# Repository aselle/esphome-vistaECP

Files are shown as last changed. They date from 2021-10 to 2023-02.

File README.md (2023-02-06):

# Honeywell/Ademco Vista ECP ESPHome custom component and library

## This fork provides a PCB

This is based on work that was discussed on the main fork issues at 
https://github.com/Dilbert66/esphome-vistaECP/issues/49

Based on the work of the main fork, I created a design and pcb. At the time, the main fork did not provide a fully isolated schematic, which I wanted if I was going to use this on my system.  I invetsigated several designs and settled on this one for my uses. The issue describes a lot of the possibilites. In the end, I used 3 optocouplers and 2 transistors.
You should be able to get the board manufactured cheaply e.g. on JLCPCB.

This is provided with no warranty implied or explicit. I can not be held responsible for you using this work. While, I have tested this in my own equipment for over a year, I suspect the main fork is better tested, so I would recommend this approach only for advanced users who know how to use an oscilloscope.
 
* circuit/v1-manufacture-files
  * has gerber, pdf schematic and case stl files
* circuit/kicad
  * KiCad source for the pcb.

Here's the isolated schematic

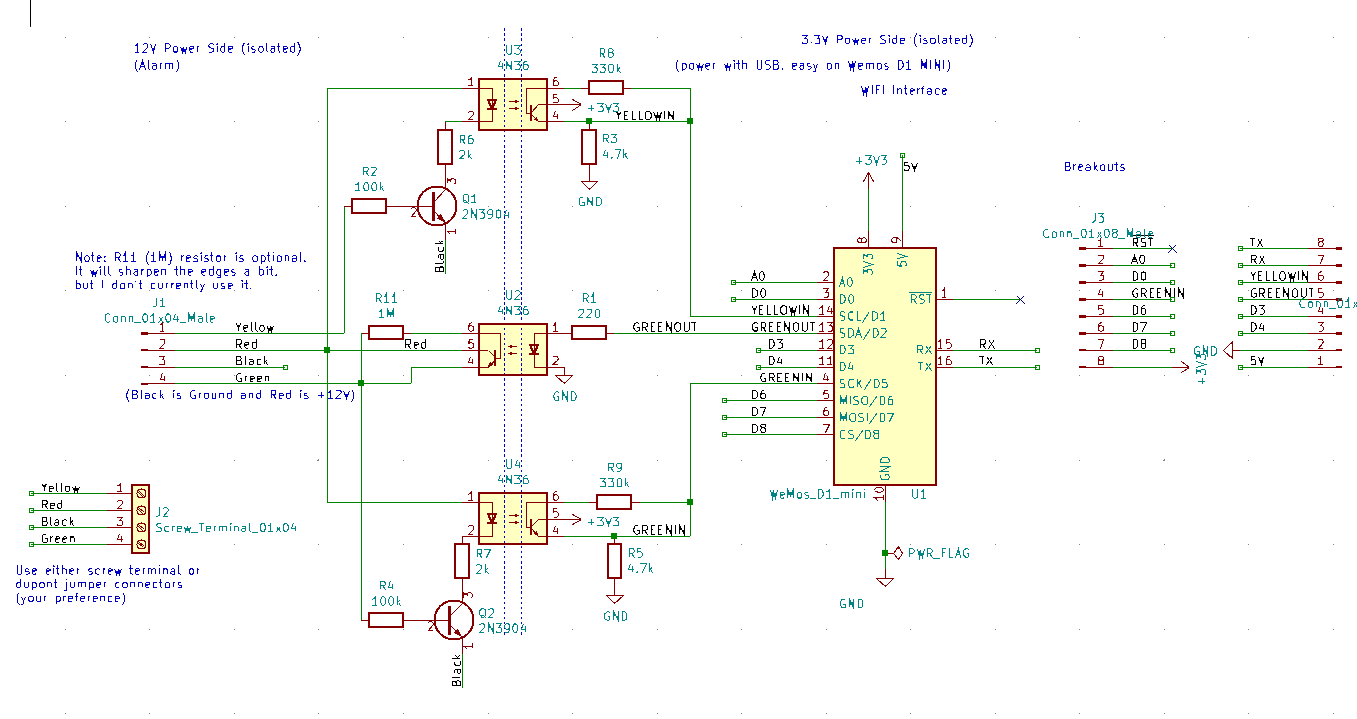
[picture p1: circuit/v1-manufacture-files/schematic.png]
Image of schematic


Here is what the manufactured product looks like

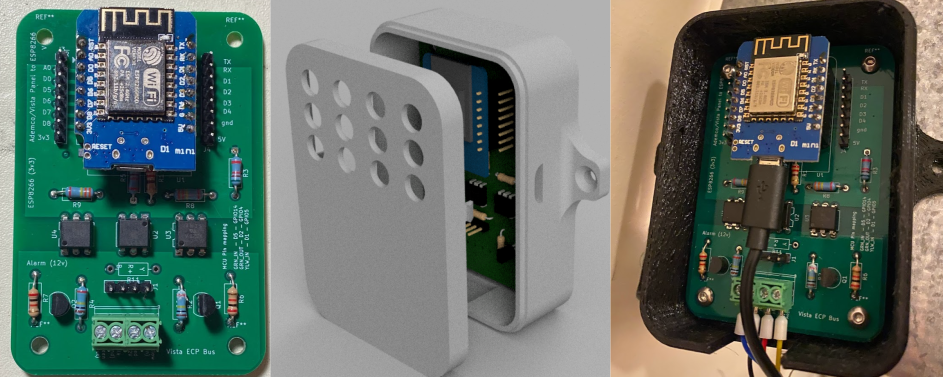
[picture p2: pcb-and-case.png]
Image of case and pcb


## Main fork documentation

This is an implementation of an ESPHOME custom component and ESP Library to interface directly to a Safewatch/Honeywell/Ademco Vista 15/20 alarm system using the ECP interface and very inexpensive ESP8266/ESP32 modules .  The ECP library code is based on the arduino source code from Mark Kimsal's repository located at  https://github.com/TANC-security/keypad-firmware.  It has been  completely rewritten as a class and adapted to work on the ESP8266/ESP32 platform using interrupt driven communications and pulse timing. A custom modified version of Peter Lerup's ESPsoftwareserial library (https://github.com/plerup/espsoftwareserial) was also used for the serial communications to work more efficiently within the tight timing of the ESP8266 interrupt window. 

To compensate for the limitations of the minimal zone data sent by the panel, a time to live (TTL) attribute for each faulted zone was used.  The panel only sends fault messages when a zone is faulted or alarmed and does not send data when the zone is restored, therefore the TTL timer is used to reset a zone after a preset duration once it stops receiving those fault/alarm messages for that zone.  You can tweak the TTL setting in the YAML.  The default timer is set to 30 seconds.  I've also added persistent storage and recovery for zone status in the event of a power failure or reboot of the ESP.  The system will use persistent storage to recover the last known status of the zone on restart.

From documented info, it seems that some panels send an F2 command with extra system details but the panel I have here (Vista 20P version 3.xx ADT version) does not.  Only the F7 is available for zone and system status in my case but this is good enough for this purpose. 

As far as writing on the bus and the request to send pulsing sequence, most documentation only discusses keypad traffic and this only uses the the 3rd pulse.  In actuality the pulses are used as noted below depending on the device type requesting to send:
```
Panel pulse 1. Addresses 1-7, expander board (07), etc
Panel pulse 2. Addresses 8-15 - zone expanders, relay modules
Panel pulse 3. Addresses 16-23 - keypads
```
For example, a zone expander that has the address 07, will send it's address on the first pulse only and will send nothing for the 2nd and 3rd pulse.  A keypad with address 16, will send a 1 bit pulse for pulse1 and pulse2 and then it's encoded address on pulse 3. This info was determined from analysis using a zone expander board and Pulseview to monitor the bus. 

If you are not familiar with ESPHome , I suggest you read up on this application at https://esphome.io and home assistant at https://www.home-assistant.io/.   The library class itself can be used outside of the esphome and home assistant systems.  Just use the code as is without the vistalalarm.yaml and vistaalarm.h files and call it's functions within your own application.  

To use this software you simply place the vistaAlarm.yaml file in your main esphome directory, then copy the *.h and *.cpp files from the vistaEcpInterface directory to a similarly named subdirectory (case sensitive) in your esphome main directory and then compile the yaml as usual. The directory name is in the "includes:" option of the yaml.

##### Notes: 
* If you use the zone expanders and/or LRR functions, you might need to clear CHECK messages for the LRR and expanded zones from the panel on boot or restart by entering your access code followed by 1 twice. eg 12341 12341 where 1234 is your access code.

The yaml attributes should be fairly self explanatory for customization. The yaml example also shows how to setup named zones. 

## Features:

* Full zone expander emulation (4219/4229) which will give you  an additional 8 zones to the system per emulated expander plus associated relay outputs. Currently the library will provide emulation for 2 boards for a total of 16 additionals zones. You can even use free pins on the chip as triggers for those zones as well. 

* Relay module emulation. (4204). The system can support 4 module addresses for a total of 16 relay channels. 

* Long Range Radio (LRR) emulation (or monitoring) statuses for more detailed status messages

* Zone status - Open, Busy, Alarmed and Closed with named zones

* Arm, disarm or send any sequence of commands to the panel

* Status indicators - fire, alarm, trouble, armed stay, armed away, instant armed, armed night,  ready, AC status, bypass status, chime status,battery status, check status, zone and relay channel status fields.

* Optional ability to monitor other devices on the bus such as keypads, other expanders, relay boards, RF devices, etc. This requires the #define MONITORTX to be uncommented in vista.h as well as the addition of two resistors (R4 and R5) to the circuit as shown in the schematic.   This adds another serial interrupt routine that captures and decodes all data on the green tx line.  If enabled this data will be used to update zone statuses for external modules.

The following services are published to home assistant for use in various scripts. 

	alarm_disarm: Disarms the alarm with the user code provided, or the code specified in the configuration.
	alarm_arm_home: Arms the alarm in home mode.
	alarm_arm_away: Arms the alarm in away mode.
	alarm_arm_night: Arms the alarm in night mode (no entry delay).
	alarm_trigger_panic: Trigger a panic alarm.
        alarm_trigger_fire: Trigger a fire alarm.
	alarm_keypress: Sends a string of characters to the alarm system. 

## Example in Home Assistant

Image of HASS example

The returned statuses for Home Assistant are: armed_away, armed_home, armed_night, pending, disarmed,triggered and unavailable.  

Sample Home Assistant Template Alarm Control Panel configuration with simple services (defaults to partition 1):

```
alarm_control_panel:
  - platform: template
    panels:
      safe_alarm_panel:
        name: "Alarm Panel"
        value_template: "{{states('sensor.vistaalarm_system_status')}}"
        code_arm_required: false
        
        arm_away:
          - service: esphome.vistaalarm_alarm_arm_away
                  
        arm_home:
          - service: esphome.vistaalarm_alarm_arm_home
          
        arm_night:
          - service: esphome.vistaalarm_alarm_arm_night
            data_template:
              code: '{{code}}' #if you didnt set it in the yaml, then send the code herefschema
          
        disarm:
          - service: esphome.vistaalarm_alarm_disarm
            data_template:
              code: '{{code}}'                    
```

## Services

- Basic alarm services. These services default to partition 1:

	- "alarm_disarm", Parameter: "code" (access code)
	- "alarm_arm_home" 
	- "alarm_arm_night", Parameter: "code" (access code)
	- "alarm_arm_away"
	- "alarm_trigger_panic"
	- "alarm_trigger_fire"

- Intermediate command service. Use this service if you need more versatility such as setting alarm states on any partition:

	- "set_alarm_state",  Parameters: "partition","state","code"  where partition is the partition number from 1 to 8, state is one of "D" (disarm), "A" (arm_away), "S" (arm_home), "N" (arm_night), "P" (panic) or "F" (fire) and "code" is your panel access code (can be empty for arming, panic and fire cmds )

- Generic command service. Use this service for more complex control:

	- "alarm_keypress",  Parameter: "keys" where keys can be any sequence of keys accepted by your panel. For example to arm in night mode you set keys to be "xxxx33" where xxxx is your access code. 
    
    - "set_zone_fault",Parameters: "zone","fault" where zone is a zone from 9 - 48 and fault is 0 or 1 (0=ok, 1=open)
       The zone number will depend on what your expander address is set to.

## Wiring

### Non-isolated simple version

ecpinterface

### Alternative version using transistors instead of an optocoupler for transmit

ecpinterface-noopto

### Ground Isolated version

ecpinterface-isolated

## Wiring Notes

* Optocouplers should have a minimum CTR of 50. Recommendations are the 4N35 or TLP521. You can vary the resistor values for the simple version but keep the ratio similar for the voltage dividers R2/R3 and R4/R5. R1 should not be set below 150 ohm. Resistor values are chosen to minimize load on ECP bus while still providing full output signals on the optocouplers. 
* My goal was to keep the design as simple as possible without causing any bus load or interference with maximum signal fidelity.  Since the transmit circuit required high side switching I opted to use an optocoupler since I had a few on hand and it simplified the amount of components needed but proved to have it's own issues as far as CTR requirements.  For those that would prefer not using optocouplers due to availability or other reasons, i've provided a version using transistors for the transmit circuit instead.  

## OTA updates
In order to make OTA updates, connection switch in frontend should be switched to OFF since the  ECP library is using interrupts.

## MQTT with HomeAssistant
If your preference is to use MQTT instead of ESPHOME, you can use the Arduino sketch from the MQTT-Example directory. It supports pretty much all functions of the ESPHOME implementation.  To use, edit the configuration items at the top of the file for your setup then simply put the ino and all *.h and *.cpp vista library files (from directory /src/vistaEcpInterface) in the same sketch directory and compile.  Read the comments within the sketch for more details.   The sketch also supports ArduinoOTA (https://www.arduino.cc/reference/en/libraries/arduinoota/) that will enable you to update the code via wifi once the initial upload is done.  

## Custom Alarm Panel Card

I've added a sample lovelace alarm-panel card copied from the repository at https://github.com/GalaxyGateway/HA-Cards. I've customized it to work with this ESP library's services.   I've also added two new text fields that will be used by the card to display the panel prompts the same way a real keypad does. To configure the card, just place the alarm-panel-card.js file into the /config/www directory of your homeassistant installation and add a new resource in your lovelace configuration pointing to /local/alarm-panel-card.js.  You can then configure the card as shown below. Just substitute your service name to your application.

```
type: 'custom:alarm-keypad-card'
title: Vista_ESPHOME
unique_id: vista1
disp_line1: sensor.vistaalarm_line1
disp_line2: sensor.vistaalarm_line2
scale: 1
service_type: esphome
service: vistaalarm_alarm_keypress
status_A: AWAY
status_B: STAY
status_C: READY
status_D: BYPASS
status_E: TROUBLE
status_F: ''
status_G: ''
status_H: ''
sensor_A: binary_sensor.vistaalarm_away
sensor_B: binary_sensor.vistaalarm_stay
sensor_C: binary_sensor.vistaalarm_ready
sensor_D: binary_sensor.vistaalarm_bypass
sensor_E: binary_sensor.vistaalarm_trouble
button_A: STAY
button_B: AWAY
button_C: DISARM
button_D: BYPASS
button_F: <
button_G: '>'
button_E: ' '
button_H: ' '
cmd_A:
  keys: '12343'
cmd_B:
  keys: '12342'
cmd_C:
  keys: '12341'
cmd_D:
  keys: '12346#'
cmd_E:
  keys: ''
cmd_H:
  keys: ''
cmd_F:
  keys: <
cmd_G:
  keys: '>'
key_0:
  keys: '0'
key_1:
  keys: '1'
key_2:
  keys: '2'
key_3:
  keys: '3'
key_4:
  keys: '4'
key_5:
  keys: '5'
key_6:
  keys: '6'
key_7:
  keys: '7'
key_8:
  keys: '8'
key_9:
  keys: '9'
key_star:
  keys: '*'
key_pound:
  keys: '#'
key_right:
  keys: '>'
key_left:
  keys: <
beep: sensor.vistaalarm_beeps
view_pad: true
view_display: true
view_status: true
view_status_2: true
view_bottom: true

type: 'custom:alarm-keypad-card'
title: Vista_MQTT
unique_id: vista2
disp_line1: sensor.displayline1
disp_line2: sensor.displayline2
scale: 1
service_type: mqtt
service: publish
status_A: AWAY
status_B: STAY
status_C: READY
status_E: BYPASS
status_D: TROUBLE
status_F: ''
status_G: ''
status_H: ''
sensor_A: sensor.vistaaway
sensor_B: sensor.vistastay
sensor_C: sensor.vistaready
sensor_E: sensor.vistabypass
sensor_D: sensor.vistatrouble
button_A: STAY
button_B: AWAY
button_C: DISARM
button_D: BYPASS
cmd_A:
  topic: vista/Set/Cmd
  payload: '!12343'
cmd_B:
  topic: vista/Set/Cmd
  payload: '!12342'
cmd_C:
  topic: vista/Set/Cmd
  payload: '!12341'
cmd_D:
  topic: vista/Set/Cmd
  payload: '!12346#'
key_0:
  topic: vista/Set/Cmd
  payload: '!0'
key_1:
  topic: vista/Set/Cmd
  payload: '!1'
key_2:
  topic: vista/Set/Cmd
  payload: '!2'
key_3:
  topic: vista/Set/Cmd
  payload: '!3'
key_4:
  topic: vista/Set/Cmd
  payload: '!4'
key_5:
  topic: vista/Set/Cmd
  payload: '!5'
key_6:
  topic: vista/Set/Cmd
  payload: '!6'
key_7:
  topic: vista/Set/Cmd
  payload: '!7'
key_8:
  topic: vista/Set/Cmd
  payload: '!8'
key_9:
  topic: vista/Set/Cmd
  payload: '!9'
key_star:
  topic: vista/Set/Cmd
  payload: '!*'
key_pound:
  topic: vista/Set/Cmd
  payload: '!#'
view_pad: true
view_display: true
view_status: true
view_status_2: true
view_bottom: false
beep: sensor.vistabeeps

```


### sample sensor configuration for card using mqtt
```

sensor:

  - platform: mqtt
    state_topic: "vista/Get/DisplayLine/1"
    name: "DisplayLine1"

  - platform: mqtt
    state_topic: "vista/Get/DisplayLine/2"
    name: "DisplayLine2"

  - platform: mqtt
    state_topic: "vista/Get/Status/AWAY"
    name: "vistaaway"
    
  - platform: mqtt
    state_topic: "vista/Get/Status/STAY"
    name: "vistastay"
  
  - platform: mqtt
    state_topic: "vista/Get/Status/READY"
    name: "vistaready"

  - platform: mqtt
    state_topic: "vista/Get/Status/TROUBLE"
    name: "vistatrouble"

  - platform: mqtt
    state_topic: "vista/Get/Status/BYPASS"
    name: "vistabypass"
    
  - platform: mqtt
    state_topic: "vista/Get/Status/CHIME"
    name: "vistachime"    

```

## References 
You can checkout the links below for further reading and other implementation examples. Some portions of the code in the repositories below was used in creating the library.
* https://github.com/TANC-security/keypad-firmware
* https://github.com/cweemin/espAdemcoECP
* https://github.com/TomVickers/Arduino2keypad/

This project is licensed under the Lesser General Public License version 2.1, or (at your option) any later version as per it's use of other libraries and code. Please see COPYING.LESSER for more informatio

## Disclaimer

THIS HARDWARE AND SOFTWARE IS PROVIDED BY THE COPYRIGHT HOLDERS AND CONTRIBUTORS “AS IS” AND ANY EXPRESS OR IMPLIED WARRANTIES, INCLUDING, BUT NOT LIMITED TO, THE IMPLIED WARRANTIES OF MERCHANTABILITY AND FITNESS FOR A PARTICULAR PURPOSE ARE DISCLAIMED. IN NO EVENT SHALL THE COPYRIGHT OWNER OR CONTRIBUTORS BE LIABLE FOR ANY DIRECT, INDIRECT, INCIDENTAL, SPECIAL, EXEMPLARY, OR CONSEQUENTIAL DAMAGES (INCLUDING, BUT NOT LIMITED TO, PROCUREMENT OF SUBSTITUTE GOODS OR SERVICES; LOSS OF USE, DATA, OR PROFITS; OR BUSINESS INTERRUPTION) HOWEVER CAUSED AND ON ANY THEORY OF LIABILITY, WHETHER IN CONTRACT, STRICT LIABILITY, OR TORT (INCLUDING NEGLIGENCE OR OTHERWISE) ARISING IN ANY WAY OUT OF THE USE OF THIS SOFTWARE, EVEN IF ADVISED OF THE POSSIBILITY OF SUCH DAMAGE.

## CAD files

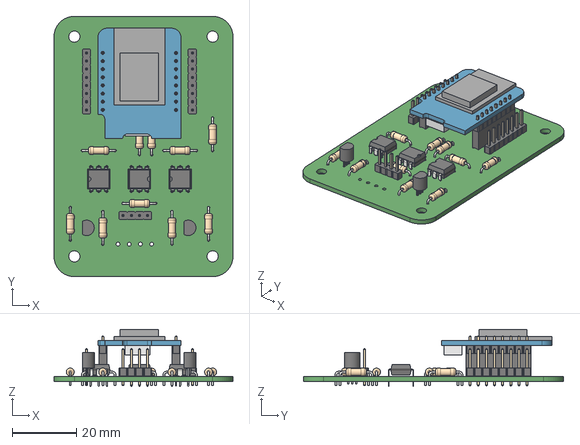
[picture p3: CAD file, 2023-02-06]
circuit/kicad/vista20p-alt.step
55.9 x 81.3 x 17.9 mm

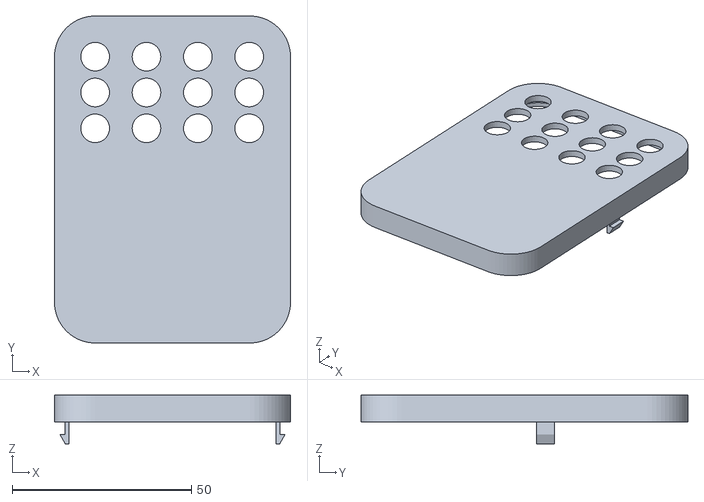
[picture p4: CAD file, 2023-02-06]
circuit/v1-manufacture-files/CaseTop.stl
65.9 x 91.3 x 13.6

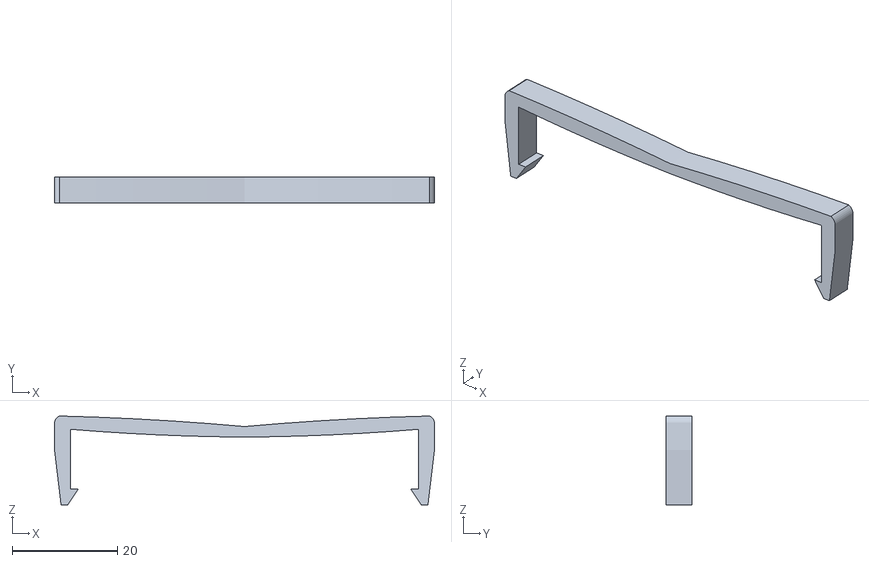
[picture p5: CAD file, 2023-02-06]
circuit/v1-manufacture-files/CaseClip.stl
72.2 x 5.00 x 16.9

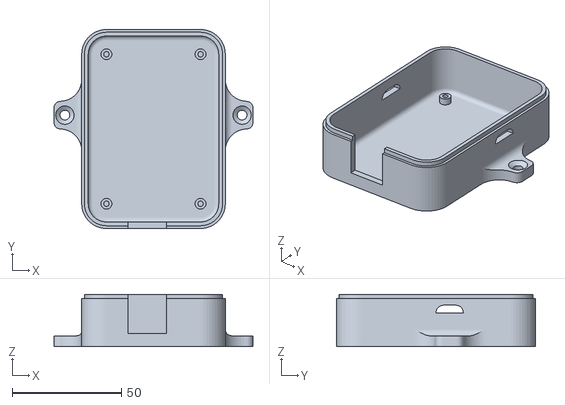
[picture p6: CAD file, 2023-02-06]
circuit/v1-manufacture-files/CaseBottom.stl
91.3 x 91.3 x 24.0

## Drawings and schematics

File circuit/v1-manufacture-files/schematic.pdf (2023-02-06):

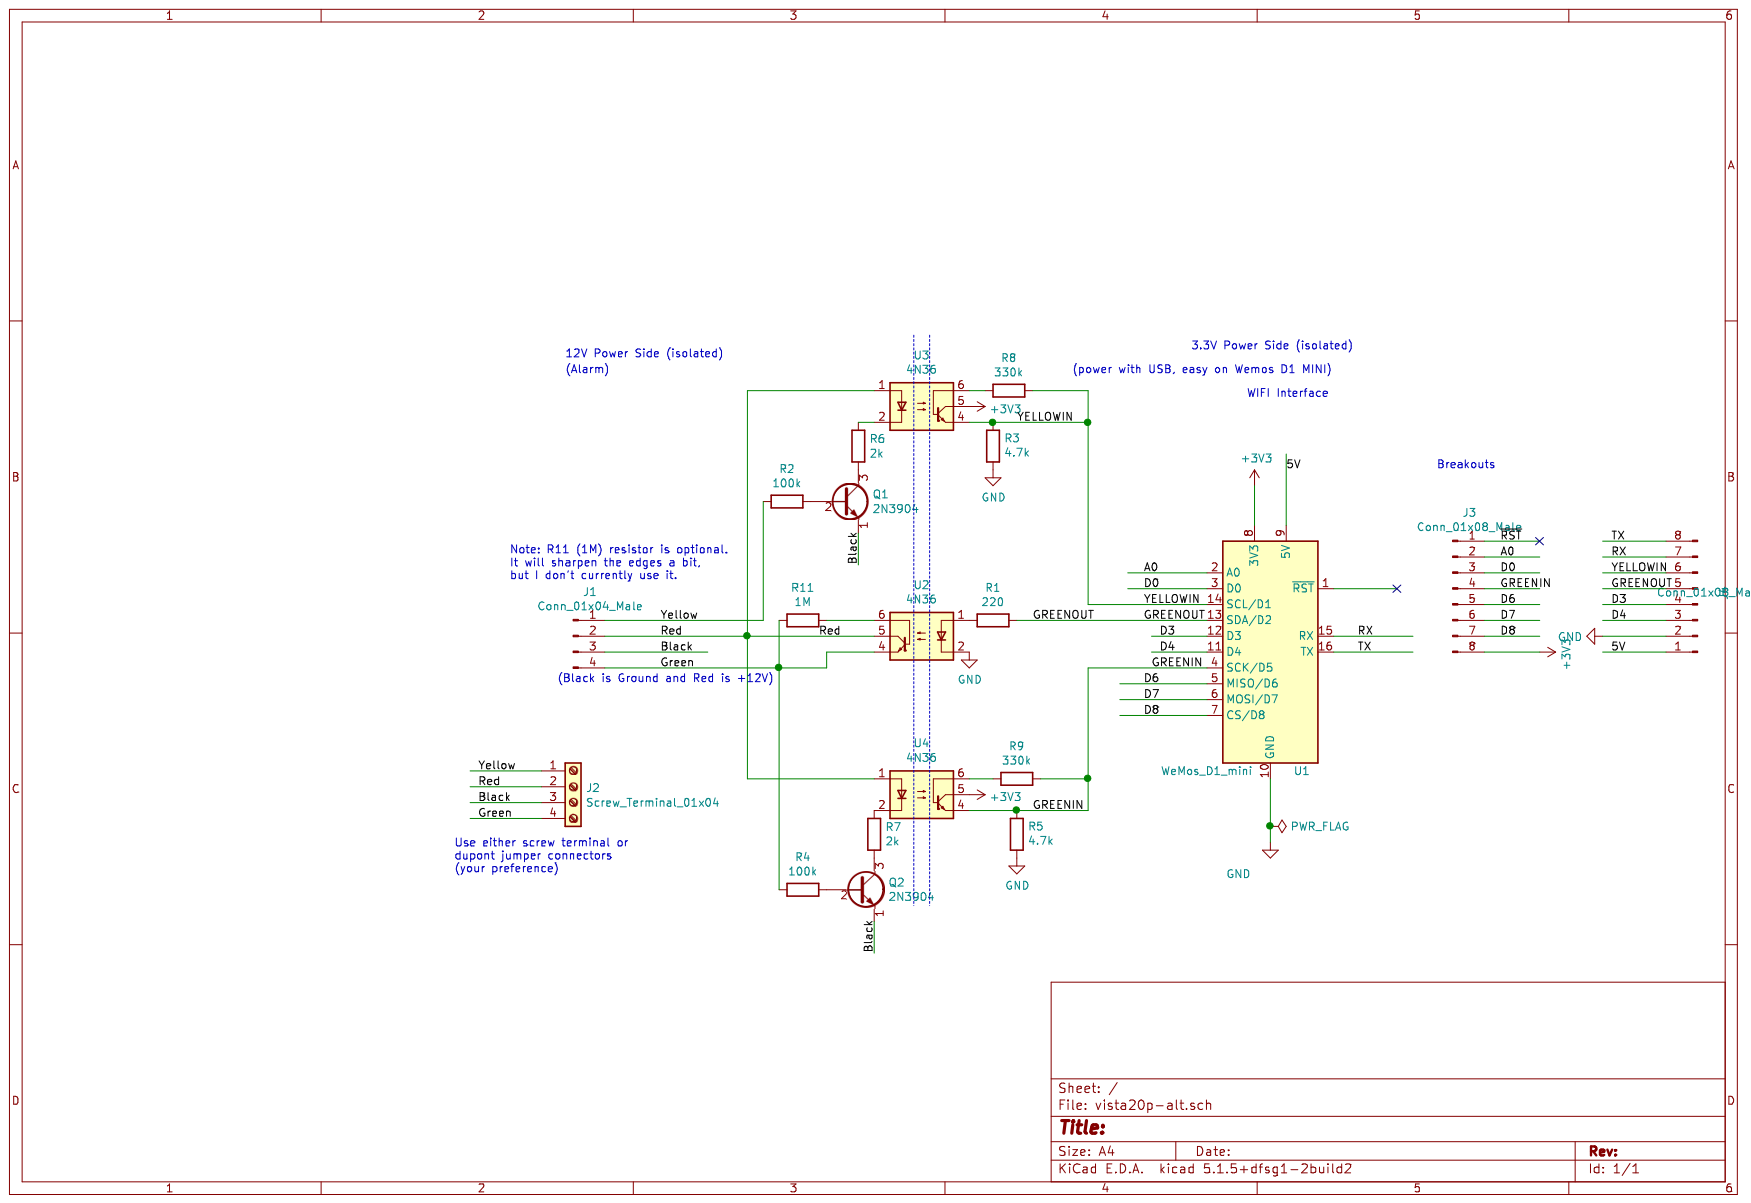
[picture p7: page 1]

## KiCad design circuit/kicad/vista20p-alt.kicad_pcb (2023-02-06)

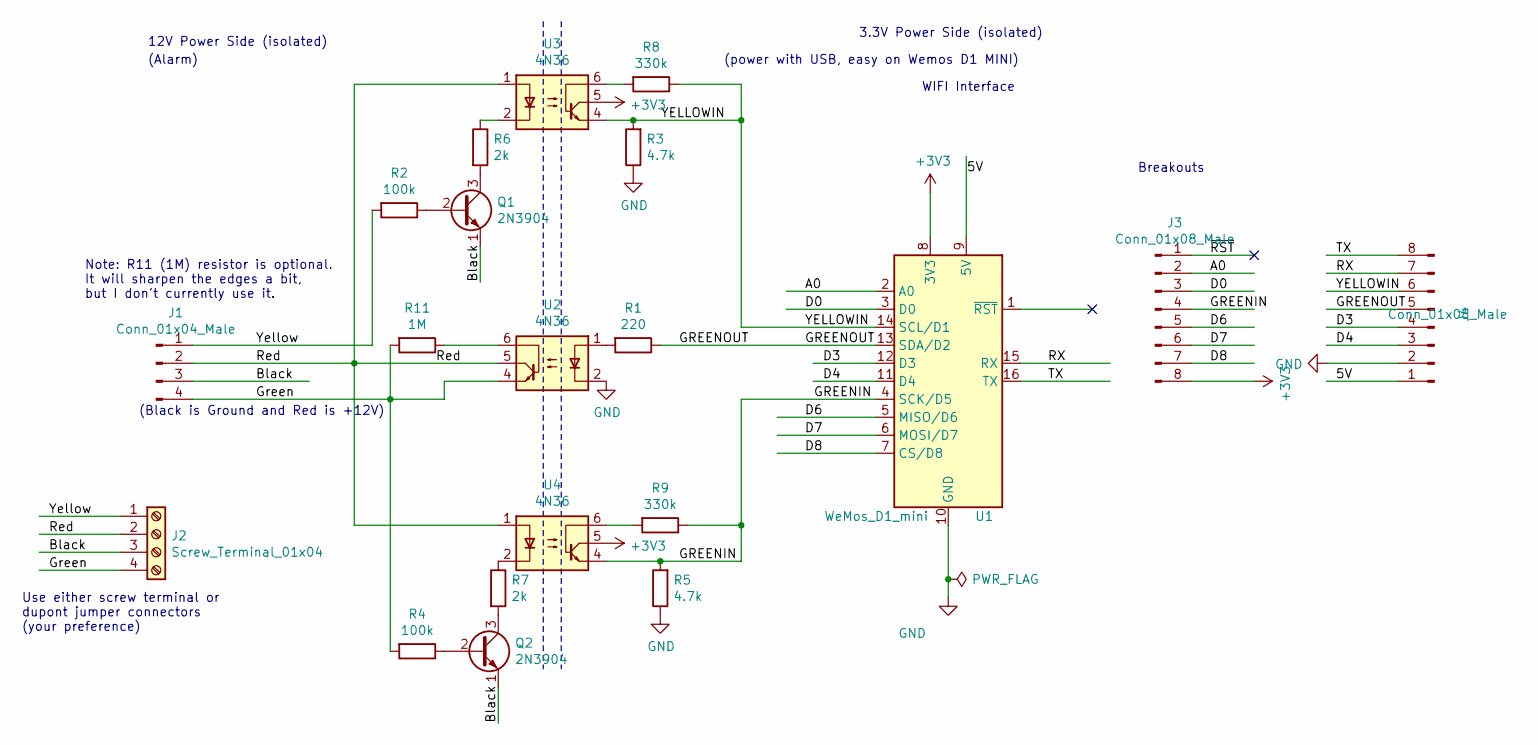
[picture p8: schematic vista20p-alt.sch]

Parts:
J1: Conn_01x04_Male; PinHeader_1x04_P2.54mm_Vertical
J2: Screw_Terminal_01x04; TerminalBlock_Phoenix_PT-1,5-4-3.5-H_1x04_P3.50mm_Horizontal
J3, J4: Conn_01x08_Male; PinHeader_1x08_P2.54mm_Vertical
Q1, Q2: 2N3904; TO-92_Inline
R1: 220; R_Axial_DIN0207_L6.3mm_D2.5mm_P10.16mm_Horizontal
R2, R4: 100k; R_Axial_DIN0207_L6.3mm_D2.5mm_P10.16mm_Horizontal
R3, R5: 4.7k; R_Axial_DIN0207_L6.3mm_D2.5mm_P10.16mm_Horizontal
R6, R7: 2k; R_Axial_DIN0207_L6.3mm_D2.5mm_P10.16mm_Horizontal
R8, R9: 330k; R_Axial_DIN0207_L6.3mm_D2.5mm_P10.16mm_Horizontal
R11: 1M; R_Axial_DIN0207_L6.3mm_D2.5mm_P10.16mm_Horizontal
U1: WeMos_D1_mini; WEMOS_D1_mini_light
U2, U3, U4: 4N36; DIP-6_W7.62mm

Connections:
+3V3: J3.8, U1.8 (3V3), U3.5, U4.5
/5V: J4.1, U1.9 (5V)
/A0: J3.2, U1.2 (A0)
/Black: J1.3, J2.3, Q1.1 (E), Q2.1 (E)
/D0: J3.3, U1.3 (D0)
/D3: J4.4, U1.12 (D3)
/D4: J4.3, U1.11 (D4)
/D6: J3.5, U1.5 (MISO/D6)
/D7: J3.6, U1.6 (MOSI/D7)
/D8: J3.7, U1.7 (CS/D8)
/GREENIN: J3.4, R5.2, R9.1, U1.4 (SCK/D5), U4.4
/GREENOUT: J4.5, R1.1, U1.13 (SDA/D2)
/Green: J1.4, J2.4, R4.2, R11.2, U2.4
/RX: J4.7, U1.15 (RX)
/Red: J1.2, J2.2, U2.5, U3.1, U4.1
/TX: J4.8, U1.16 (TX)
/YELLOWIN: J4.6, R3.2, R8.1, U1.14 (SCL/D1), U3.4
/Yellow: J1.1, J2.1, R2.2
/~RST: J3.1, U1.1 (~RST)
GND: J4.2, R3.1, R5.1, U1.10 (GND), U2.2
unnamed: Q1.2 (B), R2.1
unnamed: Q1.3 (C), R6.2
unnamed: Q2.2 (B), R4.1
unnamed: Q2.3 (C), R7.2
unnamed: R1.2, U2.1
unnamed: R6.1, U3.2
unnamed: R7.1, U4.2
unnamed: R8.2, U3.6
unnamed: R9.2, U4.6
unnamed: R11.1, U2.6

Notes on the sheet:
Use either screw terminal or dupont jumper connectors (your preference)
(power with USB, easy on Wemos D1 MINI)
WIFI Interface
(Alarm)
(Black is Ground and Red is +12V)
3.3V Power Side (isolated)
12V Power Side (isolated)
Breakouts
Note: R11 (1M) resistor is optional. It will sharpen the edges a bit, but I don't currently use it.

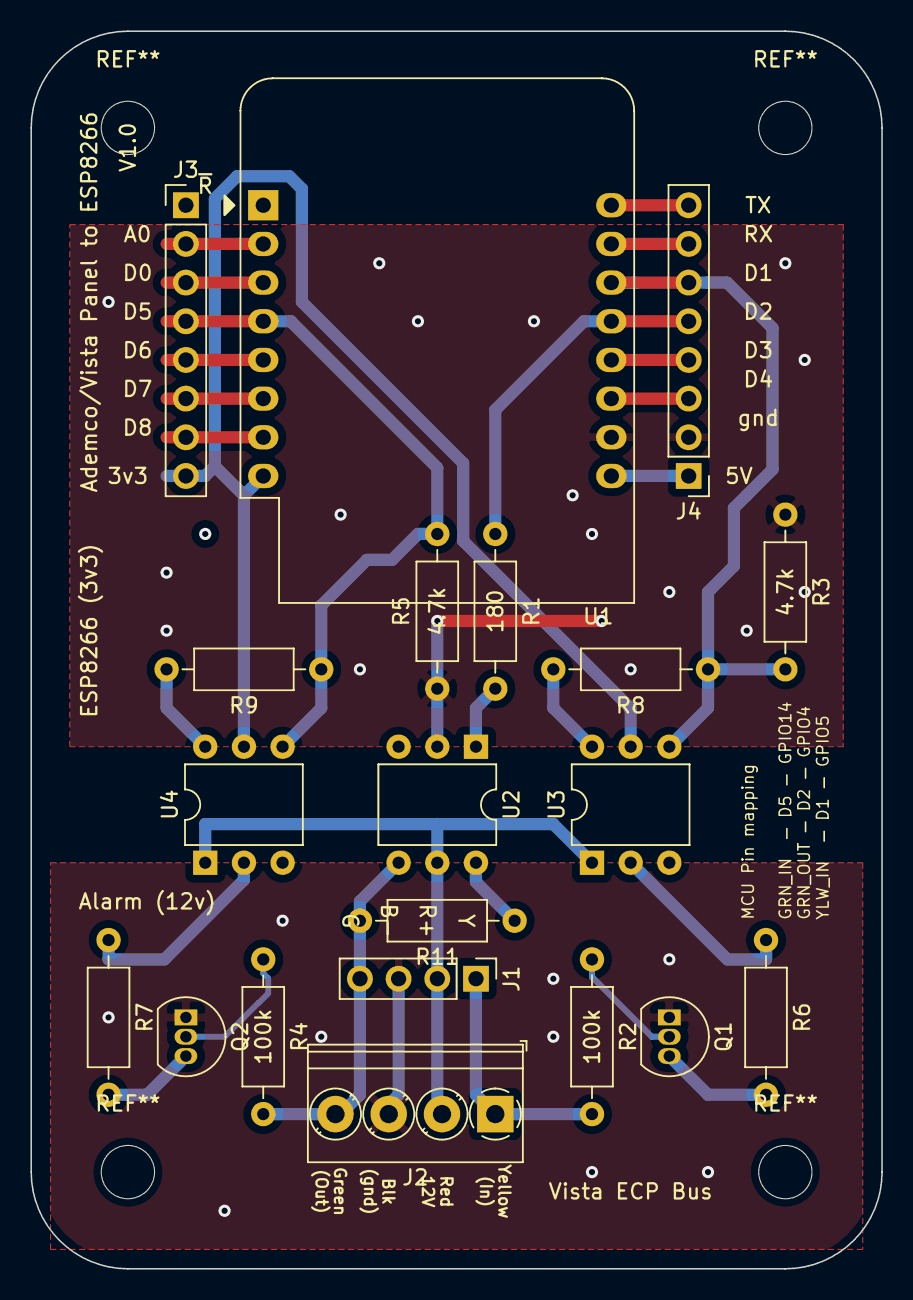
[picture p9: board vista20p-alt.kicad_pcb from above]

Board: 2 copper layers, 55.9 x 81.3 mm, 20 parts (0 on the bottom side), 30 nets.

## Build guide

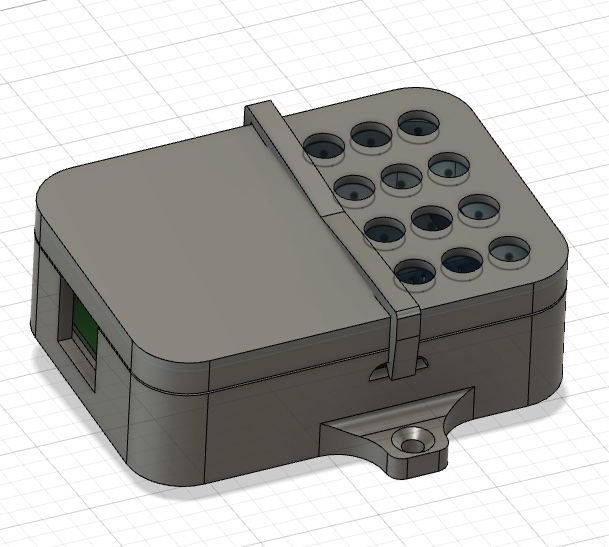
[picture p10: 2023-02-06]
circuit/v1-manufacture-files/CaseScreenshot.jpg

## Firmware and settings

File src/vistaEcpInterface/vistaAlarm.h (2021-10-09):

#include "esphome.h"

#include "vista.h"
 //for documentation see project at https://github.com/Dilbert66/esphome-vistaecp

#define KP_ADDR 16
#define MAX_ZONES 48

//default pins to use for serial comms to the panel
//The pinouts below are only examples. You can choose any other gpio pin that is available and not needed for boot.
//These have proven to work fine.
#ifdef ESP32
//esp32 use gpio pins 4,13,16-39 
#define RX_PIN 22
#define TX_PIN 21
#define MONITOR_PIN 18 // pin used to monitor the green TX line (3.3 level dropped from 12 volts
#else
#define RX_PIN 5
#define TX_PIN 4
#define MONITOR_PIN 14 // pin used to monitor the green TX line (3.3 level dropped from 12 volts
#define TX_ENABLE_PIN 12 // pin used to monitor the green TX line (3.3 level dropped from 12 volts
#endif

Stream * OutputStream = & Serial;
Vista vista(OutputStream);

void disconnectVista() {
    vista.stop();

}
enum sysState {
    soffline,
    sarmedaway,
    sarmedstay,
    sbypass,
    sac,
    schime,
    sbat,
    scheck,
    scanceled,
    sarmednight,
    sdisarmed,
    striggered,
    sunavailable,
    strouble,
    salarm,
    sfire,
    sinstant,
    sready,
    sarmed
};

class vistaECPHome: public PollingComponent, public CustomAPIDevice {
    public: vistaECPHome(char kpaddr = KP_ADDR, int receivePin = RX_PIN, int transmitPin = TX_PIN, int monitorTxPin = MONITOR_PIN, int txEnablePin=TX_ENABLE_PIN) ): kpaddr(kpaddr),
    rxPin(receivePin),
    txPin(transmitPin),
    txEnablePin(txEnablePin),
    monitorPin(monitorTxPin) {}

    // start panel language definitions
    const char *
        const FAULT = "FAULT";
    const char *
        const BYPAS = "BYPAS";
    const char *
        const ALARM = "ALARM";
    const char *
        const FIRE = "FIRE";
    const char *
        const CHECK = "CHECK";
    const char *
        const CLOSED = "CLOSED";
    const char *
        const OPEN = "OPEN";
    const char *
        const ARMED = "ARMED";

    const char *
        const STATUS_ARMED = "armed_away";
    const char *
        const STATUS_STAY = "armed_home";
    const char *
        const STATUS_NIGHT = "armed_night";
    const char *
        const STATUS_OFF = "disarmed";
    const char *
        const STATUS_ONLINE = "online";
    const char *
        const STATUS_OFFLINE = "offline";
    const char *
        const STATUS_TRIGGERED = "triggered";
    const char *
        const STATUS_READY = "ready";
    //the default ha alarm panel card likes to see "unavailable" instead of not_ready when the system can't be armed
    const char *
        const STATUS_NOT_READY = "unavailable";
    const char *
        const MSG_ZONE_BYPASS = "zone_bypass_entered";
    const char *
        const MSG_ARMED_BYPASS = "armed_custom_bypass";
    const char *
        const MSG_NO_ENTRY_DELAY = "no_entry_delay";
    const char *
        const MSG_NONE = "no_messages";
    const char *
        const HITSTAR = "Hit *";
    //end panel language definitions

    std:: function < void(uint8_t,
        const char * ) > zoneStatusChangeCallback;
    std:: function < void(const char * ) > systemStatusChangeCallback;
    std:: function < void(sysState, bool) > statusChangeCallback;
    std:: function < void(const char * ) > systemMsgChangeCallback;
    std:: function < void(const char * ) > lrrMsgChangeCallback;
    std:: function < void(const char * ) > rfMsgChangeCallback;
    std:: function < void(const char * ) > line1DisplayCallback;
    std:: function < void(const char * ) > line2DisplayCallback;
    std:: function < void(std::string) > beepsCallback;
    std:: function < void(uint8_t, uint8_t, bool) > relayStatusChangeCallback;

    void onZoneStatusChange(std:: function < void(uint8_t zone,
        const char * msg) > callback) {
        zoneStatusChangeCallback = callback;
    }
    void onSystemStatusChange(std:: function < void(const char * status) > callback) {
        systemStatusChangeCallback = callback;
    }
    void onStatusChange(std:: function < void(sysState led, bool isOpen) > callback) {
        statusChangeCallback = callback;
    }
    void onSystemMsgChange(std:: function < void(const char * msg) > callback) {
        systemMsgChangeCallback = callback;
    }
    void onLrrMsgChange(std:: function < void(const char * msg) > callback) {
        lrrMsgChangeCallback = callback;
    }
    void onLine1DisplayChange(std:: function < void(const char * msg) > callback) {
        line1DisplayCallback = callback;
    }
    void onLine2DisplayChange(std:: function < void(const char * msg) > callback) {
        line2DisplayCallback = callback;
    }
    void onBeepsChange(std:: function < void(std::string beeps) > callback) {
        beepsCallback = callback;
    }
    void onRelayStatusChange(std:: function < void(uint8_t addr, uint8_t zone, bool state) > callback) {
        relayStatusChangeCallback = callback;
    }
    void onRfMsgChange(std:: function < void(const char * msg) > callback) {
        rfMsgChangeCallback = callback;
    }

    byte debug;
    char kpaddr;
    int rxPin;
    int txPin;
    int txEnablePin;
    int monitorPin;
    const char * accessCode;
    bool quickArm;
    bool displaySystemMsg = false;
    bool lrrSupervisor,
    vh;
    char expanderAddr1,
    expanderAddr2,
    expanderAddr3,
    expanderAddr4,
    expanderAddr5,
    relayAddr1,
    relayAddr2,
    relayAddr3,
    relayAddr4;
    int TTL = 30000;

    long int x;
    enum zoneState {
        zopen,
        zclosed,
        zbypass,
        zalarm,
        zfire,
        ztrouble
    };

    sysState currentSystemState,
    previousSystemState;

    private: uint8_t zone;
    bool sent;
    char p1[18];
    char p2[18];

    std::string lastp1;
    std::string lastp2;
    int lastbeeps;
    char msg[50];

    //add zone ttl array.  zone, last seen (millis)
    struct {
        unsigned long time;
        zoneState state;
    }
    zones[MAX_ZONES + 1];

    unsigned long lowBatteryTime;

    struct alarmStatus {
        unsigned long time;
        bool state;
        uint8_t zone;
        char prompt[17];
    };

    struct {
        unsigned long time;
        bool state;
        uint8_t zone;
        char p1[17];
        char p2[17];
    }
    systemPrompt;

    struct lrrType {
        int code;
        uint8_t qual;
        uint8_t zone;
        uint8_t user;
        uint8_t partition;
    };

    struct lightStates {
        bool away;
        bool stay;
        bool night;
        bool instant;
        bool bypass;
        bool ready;
        bool ac;
        bool chime;
        bool bat;
        bool alarm;
        bool check;
        bool fire;
        bool canceled;
        bool trouble;
        bool armed;
    };

    lightStates currentLightState,
    previousLightState;
    enum lrrtype {
        user_t,
        zone_t
    };

    std::string previousMsg;
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

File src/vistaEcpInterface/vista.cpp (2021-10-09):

#include "vista.h"

#include "Arduino.h"

Vista * pointerToVistaClass;

void ICACHE_RAM_ATTR rxISRHandler() { // define global handler
    pointerToVistaClass -> rxHandleISR(); // calls class member handler
}

#ifdef MONITORTX
void ICACHE_RAM_ATTR txISRHandler() { // define global handler
    pointerToVistaClass -> txHandleISR(); // calls class member handler
}
#endif

//Vista::Vista(Stream *stream):outStream(stream)
Vista::Vista(Stream * stream) {
    outStream = stream;

    #ifdef MONITORTX
    szExt = 20;
    extbuf = (char * ) malloc(szExt);
    extcmd = (char * ) malloc(szExt);
    #endif

    szOutbuf = 20;
    szCbuf = 50;
    inbufIdx = 0;
    outbufIdx = 0;
    rxState = sNormal;
    pointerToVistaClass = this;
    cbuf = (char * ) malloc(szCbuf);
    outbuf = (char * ) malloc(szOutbuf);
    szFaultQueue = 10;
    faultQueue = (expanderType * ) malloc(szFaultQueue);
    lrrSupervisor = false;

}

Vista::~Vista() {
    free(vistaSerial);
    detachInterrupt(rxPin);
    #ifdef MONITORTX
    if (vistaSerialMonitor -> isValidGPIOpin(monitorPin)) {
        free(vistaSerialMonitor);
        detachInterrupt(monitorPin);
    }
    #endif
    pointerToVistaClass = NULL;
}
expanderType Vista::getNextFault() {
    expanderType currentFault;
    if (inFaultIdx == outFaultIdx) return currentFault;
    currentFault = faultQueue[outFaultIdx];
    outFaultIdx = (outFaultIdx + 1) % szFaultQueue;
    return currentFault;
}

expanderType ICACHE_RAM_ATTR Vista::peekNextFault() {
    expanderType currentFault;
    if (inFaultIdx == outFaultIdx) return currentFault;
    return faultQueue[outFaultIdx];
}

void Vista::setNextFault(expanderType rec) {

    int next = (inFaultIdx + 1) % szFaultQueue;
    faultQueue[inFaultIdx] = rec;
    inFaultIdx = next;
}

void Vista::readChar(char buf[], int * idx) {
    char c;
    int idxval = * idx;
    while (!vistaSerial -> available());
    c = vistaSerial -> read();
    buf[idxval++] = c;
    * idx = idxval;
}

uint8_t Vista::readChars(int ct, char buf[], int * idx, int limit) {
    char c;
    int x = 0;
    int idxval = * idx;
    if (ct > limit) return 1;
    while (x < ct) {
        if (vistaSerial -> available()) {
            c = vistaSerial -> read();
            buf[idxval++] = c;
            x++;
        }
    }
    * idx = idxval;
    return 0;
}

void Vista::clearExpect() {
    expectByte = 0;
    expectCallbackComplete = NULL;
    expectCallbackError = NULL;

}

bool Vista::onResponseError(char data) {
    if (expectCallbackError == NULL) {
        return false;
    }
    expectCallbackError(data);
    return true;
}
/**
 * return false if no complete callback was specified
 * true otherwise
 */
bool Vista::onResponseComplete(char data) {

    if (expectCallbackComplete == NULL) {
        return false;
    }
    expectCallbackComplete(data);

    return true;
}

void Vista::onStatus(char cbuf[], int * idx) {

    //byte 2 is length of message
    //byte 3 is length of headers
    //last byte of headers is counter
    //remaining bytes are body

    //F2 messages with 18 bytes or less don't seem to have
    // any important information
    if (18 >= (uint8_t) cbuf[1]) {
        return;
    }

    //19th spot seems to be a decimal value
    //01 is disarmed
    //02 is armed
    //03 is disarmed chime
    //short armed = 2 == (uint8_t) cbuf[19];
    statusFlags.armed = (0x02 & cbuf[19]) && !(cbuf[19] & 0x01);
    //20th spot is away / stay
    // this bit is really confusing
    // it clearly switches to 2 when you set away mode
    // but it is also 0x02 when an alarm is canceled,
    // but not cleared - even if you are in stay mode.
    //11th  byte in status body

    statusFlags.away = ((0x02 & cbuf[20]) > 0);
    //21st spot is for bypass
    statusFlags.zoneBypass = ((0x02 & cbuf[21]) > 0);
    //21st spot is for bypass
    //12th byte in status_body
    //short bypass = 0x02 & status_body[12];

    //22nd spot is for alarm types
    //1 is no alarm
    //2 is ignore faults (like exit delay)
    //4 is a alarm
    //6 is a fault that does not cause an alarm
    //8 is for panic alarm.

    statusFlags.noAlarm = ((cbuf[22] & 0x01) > 0);
    statusFlags.exitDelay = ((cbuf[22] & 0x02) > 0);
    statusFlags.fault = ((cbuf[22] & 0x04) > 0);
    statusFlags.panicAlarm = ((cbuf[22] & 0x08) > 0);

    if (statusFlags.armed && statusFlags.fault && !statusFlags.exitDelay) {
        statusFlags.alarm = 1;
    } else if (!statusFlags.armed && statusFlags.fault && !statusFlags.exitDelay) {
        statusFlags.alarm = 0;
    }

}

void Vista::onDisplay(char cbuf[], int * idx) {
    //first is cmd number
    // next 3 bytes are addresses of intended keypads to display this message
    // from left to right MSB to LSB
    // 5th byte represents zone
    // 6th binary encoded data including beeps
    // 7th binary encoded data including status armed mode
    // 8th binary encoded data including ac power and chime
    // 9th byte Programming mode = 0x01
    // 10th byte promt position in the display message of the expected input

    for (int x = 0; x <= 10; x++) {
        switch (x) {
        case 1:
            // device addresses 0-7
            statusFlags.keypad[0] = cbuf[x];
            break;
        case 2:
            //device addresses 8 - 15
            statusFlags.keypad[1] = cbuf[x];
            break;
        case 3:
            statusFlags.keypad[2] = cbuf[x];
            //keypads 16-23
            break;
        case 4:
            statusFlags.keypad[3] = cbuf[x];
            // keypads 24-31
            break;
        case 5:
            statusFlags.zone = (uint8_t) toDec(cbuf[x]);
            break;
        case 6:
            statusFlags.beeps = cbuf[x] & BIT_MASK_BYTE1_BEEP;
            statusFlags.night = ((cbuf[x] & BIT_MASK_BYTE1_NIGHT) > 0);

            break;
        case 7:
            statusFlags.fire = ((cbuf[x] & BIT_MASK_BYTE2_FIRE) > 0);
            statusFlags.systemFlag = ((cbuf[x] & BIT_MASK_BYTE2_SYSTEM_FLAG) > 0);
            statusFlags.ready = ((cbuf[x] & BIT_MASK_BYTE2_READY) > 0);
            if (statusFlags.systemFlag) {
                statusFlags.armedStay = ((cbuf[x] & BIT_MASK_BYTE2_ARMED_HOME) > 0);
                statusFlags.lowBattery = ((cbuf[x] & BIT_MASK_BYTE2_LOW_BAT) > 0);
                statusFlags.acLoss = ((cbuf[x] & BIT_MASK_BYTE2_AC_LOSS) > 0);
            } else {
                statusFlags.check = ((cbuf[x] & BIT_MASK_BYTE2_CHECK_FLAG) > 0);
                statusFlags.fireZone = ((cbuf[x] & BIT_MASK_BYTE2_ALARM_ZONE) > 0);
            }
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

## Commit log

2021-10-09 Add parameter for txEnablePin
    This uses existing functionality to drive a pin indicating when any driver of the
    tx output of the microcontroller should be driven. This allows the esp8266 impersonation
    to drive the pin harder when it is transmitting, improving signal integrity.
    This is probably not needed by most users.
2023-02-06 Add pcb, case, and new description
    [CaseBottom.stl, CaseClip.stl, CaseTop.stl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]
2023-02-08 Remove old gerbers from the kicad directory
    [vista20p-alt-B_Cu.gbr, vista20p-alt-B_Mask.gbr, vista20p-alt-B_Paste.gbr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]
